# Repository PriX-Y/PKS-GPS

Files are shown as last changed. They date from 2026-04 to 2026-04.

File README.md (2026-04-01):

# **PKS-GPS**

GPS module with custome PCB and Case

I made becuse i need gps in my GPS to my project but i dont wanna put this in **BIG Project**
there is not anntena becuse for now i dont need. I made this i track road and speed
for that moment i no need code for it
# there is visual in a case:

Zrzut ekranu 2026-03-31 222147

Zrzut ekranu 2026-03-31 222155

and closed

Zrzut ekranu 2026-03-31 222237

im not use screaw becuse its  small ( 30mm ) and i use hot glue to close that

# **Parts**

** Is base on uBLOK MAX-M10S gps mcu its cheap but very good ** 

Zrzut ekranu 2026-03-31 180802

Zrzut ekranu 2026-03-31 181203

** i give to it 2.54mm pin conector becuse i need something to connect i think its a little to big for this project but work , work **

 ** red diod what i have for free from my arduino **

** capacitors and resistors is smd yeah but in 805 case and i wanna teach how to sold smd becuse is harder then tht **

this connector for connector its cheap and good :)

that all parts

# Programs

kicad(pcb)

google dosc (bom)

# there is BOM 

**Parts from kicad:**


**Parts to buy BOM**
Zrzut ekranu 2026-04-01 014924

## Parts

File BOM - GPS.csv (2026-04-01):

Component | Amount | Cost | Shop | Link
u-blox MAX-M10S-00B | 1 | $24.09 | tme.eu | https://www.tme.eu/pl/details/max-m10s-00b/moduly-gnss-gps/u-blox/
MMCX-12 Connector | 1 | $2.47 | tme.eu | https://www.tme.eu/pl/details/mmcx-12/zlacza-mcx-mmcx/ninigi/
Capacitors (0805 Mix) kit | 1 | $4.02 | tme.eu
Resistors (0805 & 0402 Mix) kit | 1 | $3.86 | tme.eu
Goldpins Right-Angle 40 | 1 | $0.95 | tme.eu | https://www.tme.eu/pl/details/zl211-40kg/listwy-i-gniazda-kolkowe/connfly/ds1022-1-40rdf11-b/
Jlbpcb PCb + Delivery + tax | 1 | $6.89 | jlbpcb.com

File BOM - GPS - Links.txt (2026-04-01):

https://www.tme.eu/pl/details/smd0805-10k-1%25/rezystory-smd/royalohm/0805s8f1002t5e/

https://www.tme.eu/pl/details/zl211-40kg/listwy-i-gniazda-kolkowe/connfly/ds1022-1-40rdf11-b/

https://www.tme.eu/pl/details/smd0805-4k7-1%25/rezystory-smd/royalohm/0805s8f4701t5e/

https://www.tme.eu/pl/details/smd0805-1k-1%25/rezystory-smd/royalohm/0805s8f1001t5e/

https://www.tme.eu/pl/details/cl21a226maynnne/kondensatory-mlcc-smd/samsung/

https://www.tme.eu/pl/details/cl21b105kbfnnne/kondensatory-mlcc-smd/samsung/

https://www.tme.eu/pl/details/08055c104kat2a/kondensatory-mlcc-smd/kyocera-avx/

https://www.tme.eu/pl/details/max-m10s-00b/moduly-gnss-gps/u-blox/

https://www.tme.eu/pl/details/mmcx-12/zlacza-mcx-mmcx/ninigi/

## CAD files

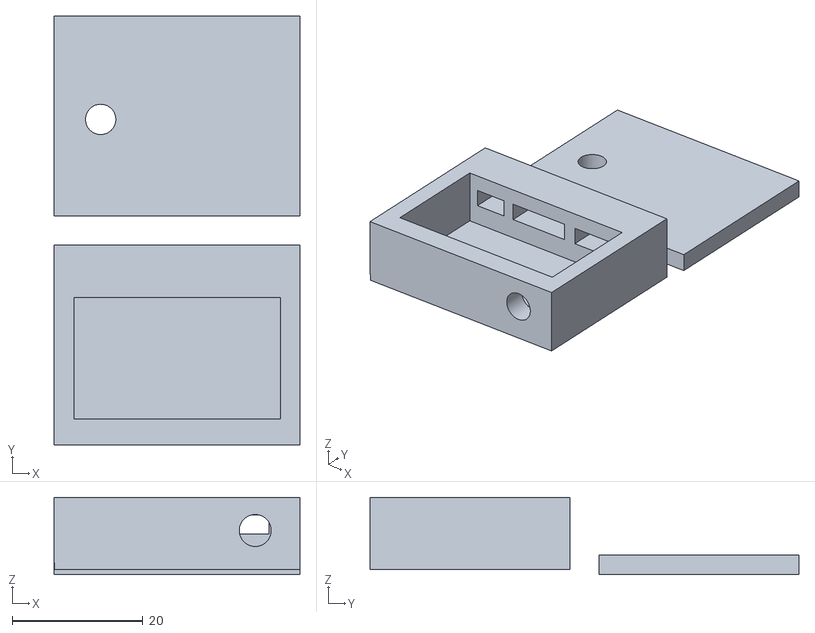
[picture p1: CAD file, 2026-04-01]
Cad File - GPS/Gps-Case-3d.stl
37.6 x 65.5 x 11.8

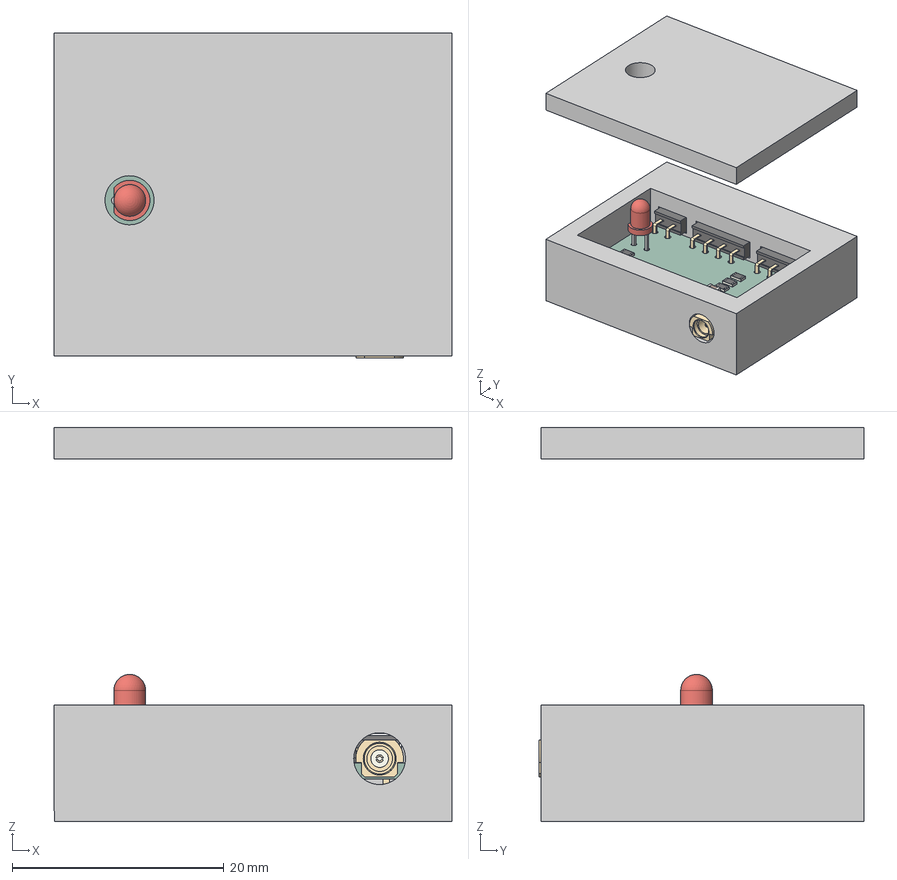
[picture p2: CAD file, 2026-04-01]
Cad File - GPS/Visual GPS+case.step.step
37.6 x 30.7 x 37.2 mm

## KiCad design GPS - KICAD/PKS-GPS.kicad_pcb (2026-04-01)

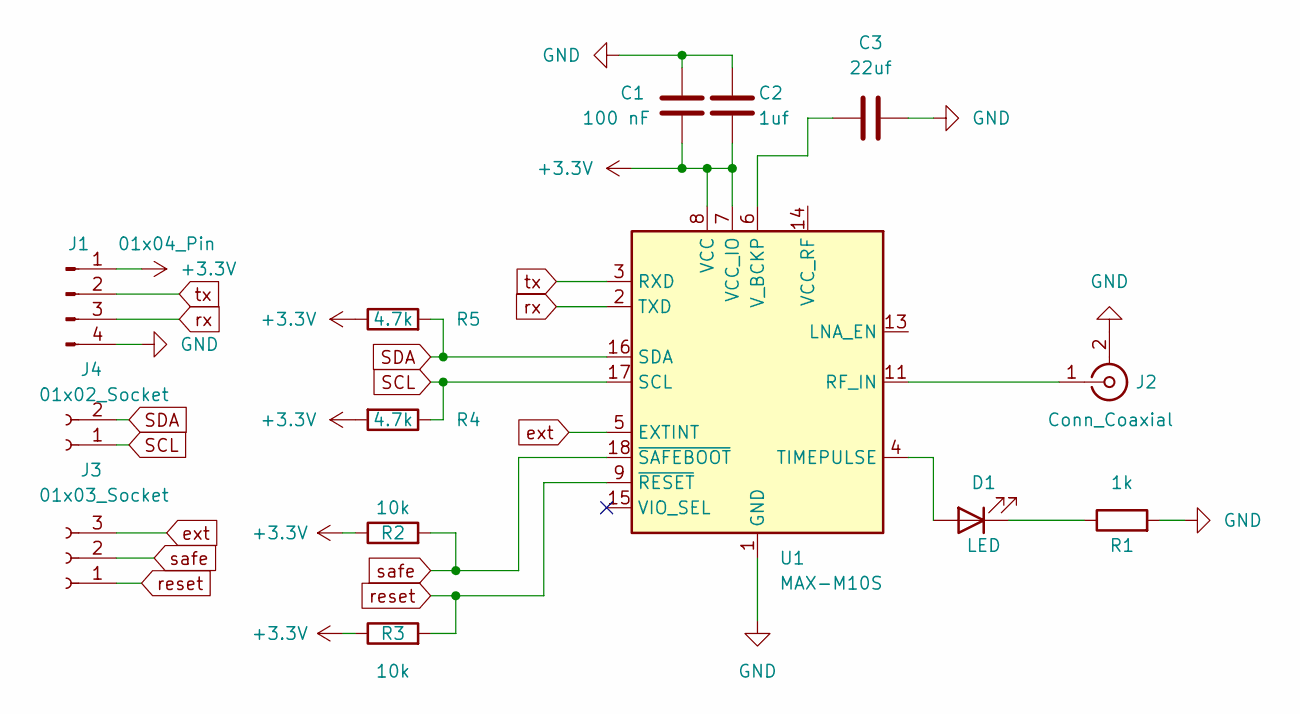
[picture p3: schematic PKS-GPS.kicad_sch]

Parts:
C1: 100 nF; C_0805_2012Metric_Pad1.18x1.45mm_HandSolder
C2: 1uf; C_0805_2012Metric_Pad1.18x1.45mm_HandSolder
C3: 22uf; C_0805_2012Metric_Pad1.18x1.45mm_HandSolder
D1: LED; LED_D3.0mm
J1: 01x04_Pin; PinSocket_1x04_P2.54mm_Horizontal
J2: Conn_Coaxial; MMCX_Molex_73415-0961_Horizontal_1.6mm-PCB
J3: 01x03_Socket; PinSocket_1x03_P2.54mm_Horizontal
J4: 01x02_Socket; PinSocket_1x02_P2.54mm_Horizontal
R1: 1k; R_0805_2012Metric_Pad1.20x1.40mm_HandSolder
R2, R3: 10k; R_0805_2012Metric_Pad1.20x1.40mm_HandSolder
R4, R5: 4.7k; R_0805_2012Metric_Pad1.20x1.40mm_HandSolder
U1: MAX-M10S; ublox_MAX

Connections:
+3.3V: C1.2, C2.2, J1.1, R2.1, R3.1, R4.2, R5.1, U1.7 (VCC_IO), U1.8 (VCC)
GND: C1.1, C2.1, C3.1, J1.4, J2.2 (Ext), R1.2, U1.1 (GND), U1.10 (GND), U1.12 (GND)
unnamed: D1.2 (A), U1.4 (TIMEPULSE)
unnamed: D1.1 (K), R1.1
unnamed: J2.1 (In), U1.11 (RF_IN)
unnamed: C3.2, U1.6 (V_BCKP)
SCL: J4.1, R4.1, U1.17 (SCL)
SDA: J4.2, R5.2, U1.16 (SDA)
ext: J3.3, U1.5 (EXTINT)
reset: J3.1, R3.2, U1.9 (~RESET)
rx: J1.3, U1.2 (TXD)
safe: J3.2, R2.2, U1.18 (~SAFEBOOT)
tx: J1.2, U1.3 (RXD)

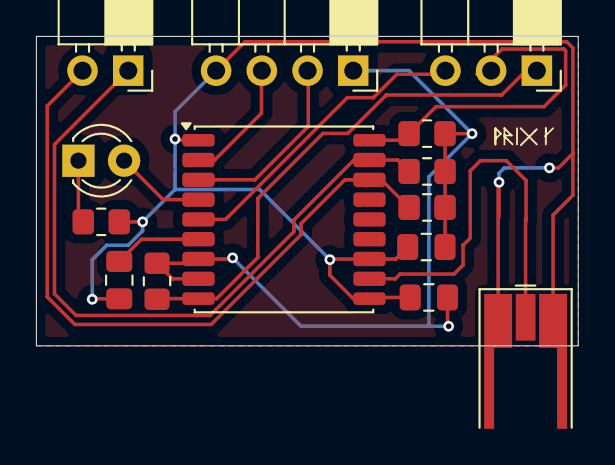
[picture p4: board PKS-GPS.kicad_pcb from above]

Board: 2 copper layers, 30.1 x 17.2 mm, 14 parts (0 on the bottom side), 13 nets.
